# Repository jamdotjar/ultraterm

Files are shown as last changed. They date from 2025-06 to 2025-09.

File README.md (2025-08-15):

# ULTRATERM
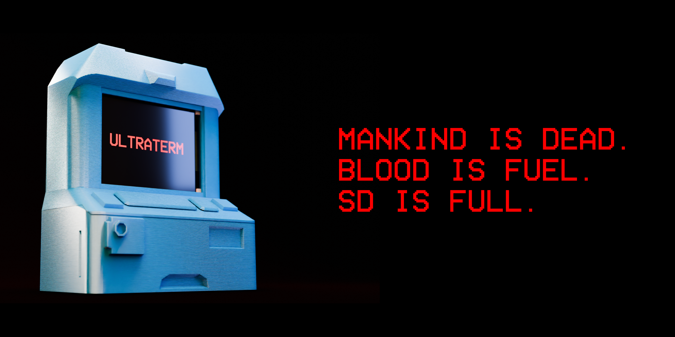
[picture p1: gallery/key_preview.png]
Hero image


ULTRATERM is a miniature replica of an ULTRAKILL settings terminal ( like the one used in cybergrind ), that acts as a bluetooth audio player.

> ***NOTE**: This project is built, but there's still work to do. Check out the [journal](JOURNAL.md) for progress updates! Right now I'm:* `bashing together some code`

## Design

The terminal sits at around 125mm tall, with a 57x104mm footprint. It was designed to look cool, be fairly accurate, and act as a (mostly) stand alone device. It features a:
- 2.8" TFT display
- Touchscreen + 3 physical buttons
- A 2000mAh battery
- Bluetooth headphone support
- USB-C storage interface
- Removable SD card storage ( and a custom microSD card adapter )
The case is designed to be entirely 3D printable, and assembled without adhesive or fasteners.
While the terminal isn't a perfect replica, it's decently close. ( for example, there's none of the wires near the top, but there is a magnetic attachment point so I *can* add them )

This project was made as mostly a fun intro to custom hardware. I've made keyboards before, but design wise those are fairly simplec ( this isn't much more complicated ). I decided to model it after the ULTRAKILL Cybergrind terminal because that's the one that handles  cybergrind music ingame ( and because its form factor is also a *lot* more forgiving to fit everything into )

If you happen to try and make your own, I'd suggest either 3d-printing it in blue for minimum effort, or printing it in grey, painting it, then scuffing the paint to give it the worn look it has in-game. ( also check out the assembly section )

I'm still hacking away at getting everything working, but here's a video demo of my progress so far:

Video (https://www.youtube.com/watch?v=Mtm72WqqxwA)

## Gallery

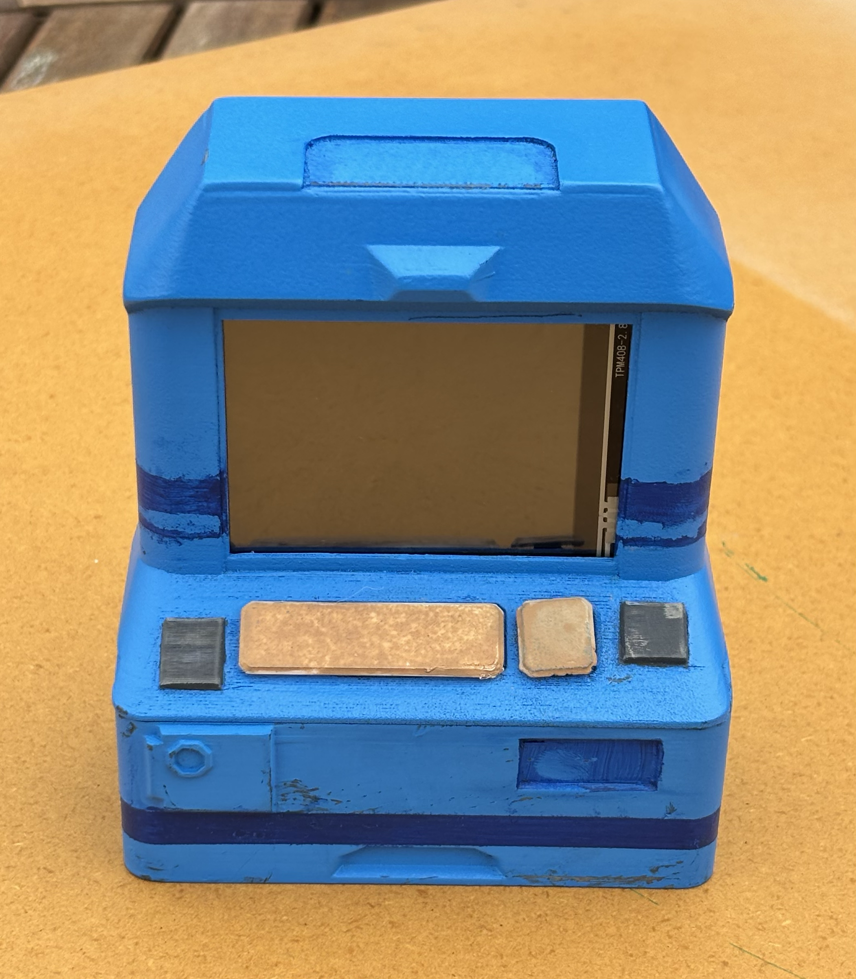
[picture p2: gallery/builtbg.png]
Assebled on tan bg

ULTRATERM back IO render product render on black background
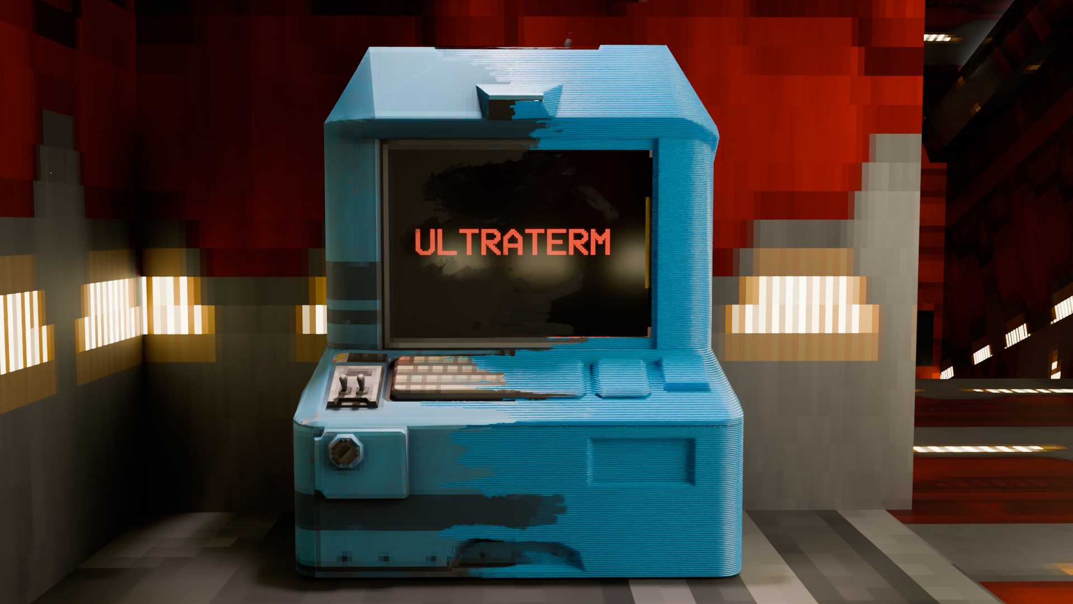
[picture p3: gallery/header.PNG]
ULTRATERM product render in ULTRAKILL enviroment

ULTRATERM left angle product render on black background
*more in [./gallery](gallery)*

## PCB

Screenshot 2025-07-03 at 11 37 43 PM
Screenshot 2025-07-03 at 11 37 01 PM


## Case
Screenshot 2025-07-03 at 11 41 00 PM
Screenshot 2025-07-03 at 11 40 50 PM

Screenshot 2025-07-03 at 11 45 09 PM
Screenshot 2025-07-03 at 11 44 03 PM

### Wiring



## BOM 
*prices in usd, see [bom.csv](/BOM.CSV) too*
|Item |Quantity|Price|Supplier  |Notes |link |
|---|---|-----|---|---|---|
|PCB |5 |4.7  |JLCPCB | |https://jlcpcb.com/ |
|TINYPICO v2 |1 |20 | Digikey |(+20 dollar shipping, ik its really expensive, I csn cover a good bit of the cost )|https://www.mouser.com/ProductDetail/392-TP-01 |
|TZT 240x320 2.8" SPI ST7789V LCD Touch Panel|1 |7.09 |Aliexpress| |https://www.aliexpress.com/item/1005004557916570.html |
|3.7v 2000mah LiPo battery |1 |16.92|Amazon |price comparable to ali |https://www.amazon.ca/Rechargeable-Controller-CUH-ZCT1-Electronic-Bluetooth/dp/B0CG178SHB |
|Pin Headers |20 |2.00 |Aliexpress|for stupid LCD mounting soln. |https://www.aliexpress.com/item/4000873858801 |
|22Awg wire |5m |2.4  |Aliexpress|front panel mount + battery backup soln |https://www.aliexpress.com/item/1005004712828392.html |
|32gb microSD card |2 |4.7  |LCSC |second waives 3$ fee, saves 1 dollar on order total |https://lcsc.com/product-detail/Storage-products_SDTRUVAL-SDSDQAD-016G-SDWCK_C42416577.html |
|32gb SD card |1 |5.8  |LCSC | |https://lcsc.com/product-detail/Storage-products_MK-MKSD032G-CGT1A_C22374946.html |
|LM809 |1 |0.66 |LCSC | |https://lcsc.com/product-detail/Supervisor-and-Reset-ICs_Texas-Instruments-LM809M3X-4-38-NOPB_C544520.html|
|JST-PH-2 |10 |0.59 |LCSC | |https://lcsc.com/product-detail/Wire-To-Board-Connector_JST-B2B-PH-K-K-LF-SN_C265438.html |
|SPDT slide switch |20 |0.48 |LCSC | |https://lcsc.com/product-detail/Slide-Switches_SHOU-HAN-SK12D07VG4_C393937.html |
|6mm pushbutton |50 |0.84 |LCSC | |https://lcsc.com/product-detail/Tactile-Switches_SHOU-HAN-TS665CJ_C393938.html |
|Amphenol 10067847-001RLF |1 |1.31 |LCSC | |https://lcsc.com/product-detail/SD-Card-Memory-Card-Connector_Amphenol-ICC-10067847-001RLF_C569097.html |
|Hirose C719027 |1 |1.04 |LCSC | |https://lcsc.com/product-detail/SD-Card-Memory-Card-Connector_HRS-Hirose-DM3D-SF_C719027.html |
|LCSC Shipping | |12.88|LCSC | | |
|Total |1 |95.21| | | |
## Assembly

Putting this together is relatively simple, the hardest part is connecting the screen and front panel before putting the two halves together. Assuming you aren't too rough, the mounting holes for the screen and button panels should be enough to hold them. A small dab of superglue can help make sure they don't come out with repeated use. I'd advise dupont cables or soemthing similar to connect the screen, as long as it has a lot of slack it should be fine ( the case has a lot of empty space to wind the cables into )
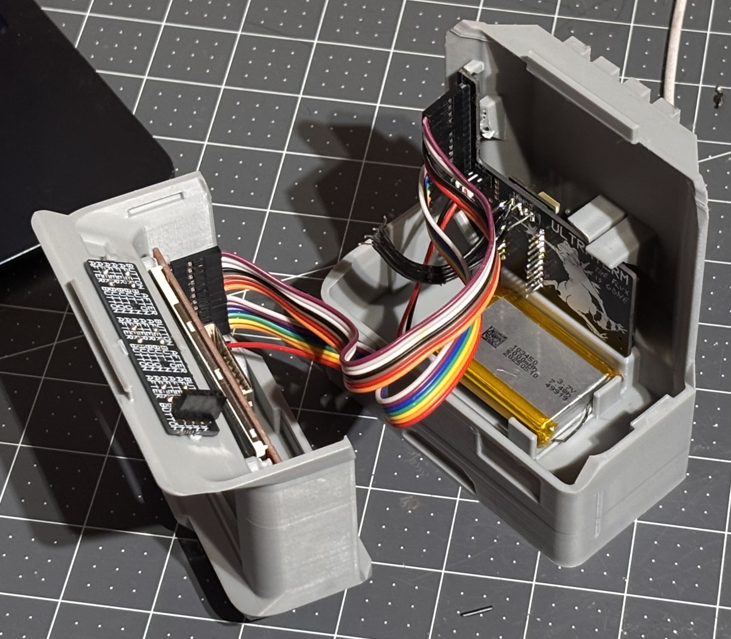
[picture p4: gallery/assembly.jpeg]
Assebled halfway


## LICENSE

This project uses the [CC-BY-SA-4.0](https://creativecommons.org/licenses/by-sa/4.0/) for all firmware, documentation, renders, and other writing. Hardware including all Case and PCB designs, is licensed under the [CERN-OHL-W v2](https://ohwr.org/cern_ohl_w_v2.txt)
> This project was heavily inspired by the game ULTRAKILL, created by Hakita (Arsi "Hakita" Patala). The ULTRATERM design, as well as some assets used in renders are derived from or inspired by ULTRAKILL.
All rights to ULTRAKILL belong to Hakita and New Blood Interactive. This project is not affiliated with or endorsed by Hakita or New Blood. 
( [ULTRAKILL is a banger game, you should totally get it, it's like 20 bucks ](http://devilmayquake.com))

This project was made for [*highway*](https://highway.hackclub.com)

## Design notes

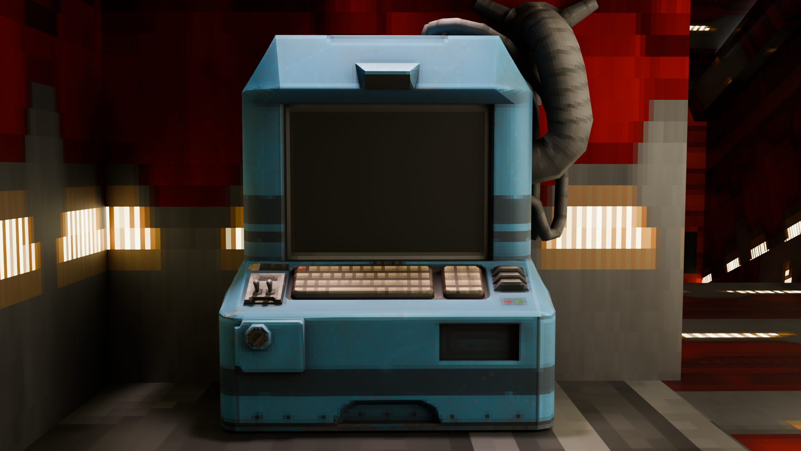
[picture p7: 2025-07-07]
gallery/ent-original.png

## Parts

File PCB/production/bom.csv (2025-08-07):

Designator | Footprint | Quantity | Value | LCSC Part #
J4 | SD_Card_Device_16mm_SlotDepth | 1 | SD_Card_Device
J5 | microSD_HC_Hirose_DM3D-SF | 1 | Micro_SD_Card

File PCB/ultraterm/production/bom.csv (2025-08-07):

Designator | Footprint | Quantity | Value | LCSC Part #
J1 | PinHeader_1x14_P2.54mm_Vertical | 1 | ILI9341
J2 | JST_PH_B2B-PH-K_1x02_P2.00mm_Vertical | 1 | Battery_plug
J3 | AMPHENOL_10067847-001RLF | 1 | SD_Card_Receptacle
J4 | SD_Card_Device_16mm_SlotDepth | 1 | SD_Card_Device
J5 | microSD_HC_Hirose_DM3D-SF | 1 | Micro_SD_Card
LED1 | LED_D5.0mm-4_RGB_Wide_Pins | 1 | LED_5mm_RGB_Kcom_RKGB
MOUSE-BITE-3MM-SLOT_3, MOUSE-BITE-3MM-SLOT_2, MOUSE-BITE-3MM-SLOT | mouse-bite-3mm-slot | 3 | VAL**
R1 | R_Axial_DIN0207_L6.3mm_D2.5mm_P10.16mm_Horizontal | 1 | 33ohm
SW1, SW2, SW3 | SW_PUSH_6mm | 3 | SW_Push
SW4 | SW_Slide_SPDT_Angled_CK_OS102011MA1Q | 1 | SW_SPST
U2 | SOT-23 | 1 | LM809
U3 | TINYPICO | 1 | ~

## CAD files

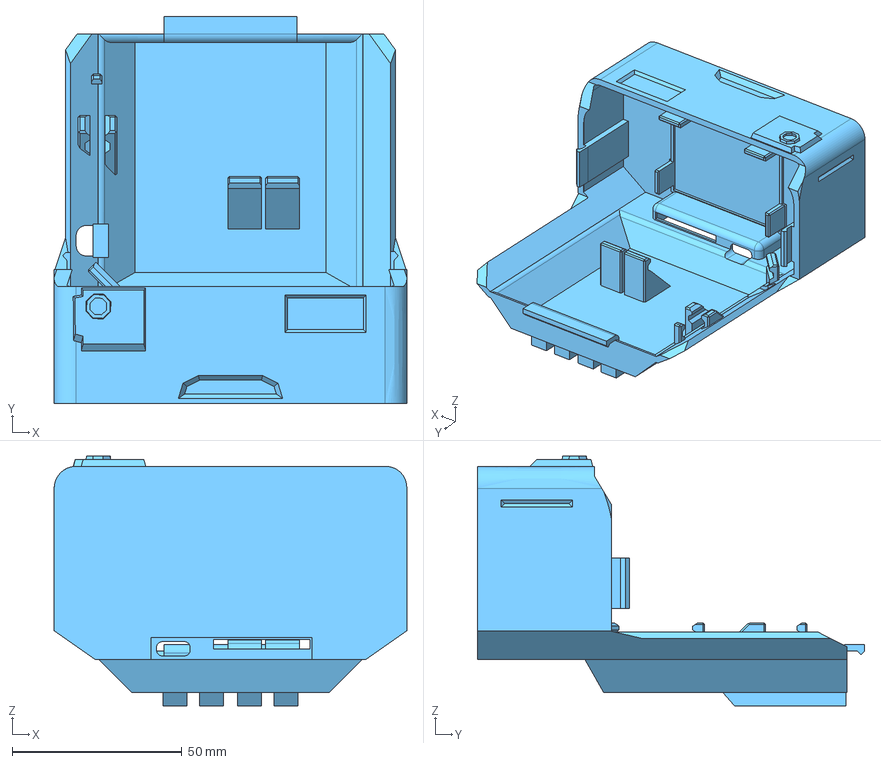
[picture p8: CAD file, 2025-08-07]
Cad/case_bottom.step
104.0 x 114.1 x 73.7 mm

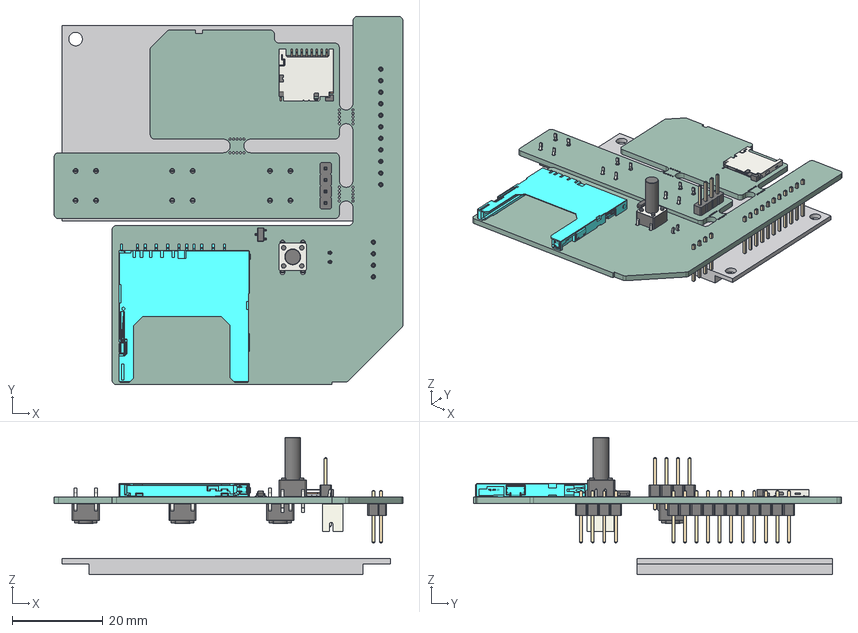
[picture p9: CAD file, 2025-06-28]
PCB/ultraterm/ultraterm.step
76.8 x 81.0 x 30.2 mm
PinHeader_1x04_P2.54mm_Vertical x 2
microSD_HC_Hirose_DM3D-SF
SD_Kyocera_145638009511859+
SW_PUSH_6mm_H13mm
SOT-23
SW_PUSH_6mm x 3
JST_PH_B2B-PH-K_1x02_P2.00mm_Vertical
PinHeader_1x11_P2.54mm_Vertical
240x320-2.4
ultraterm_PCB

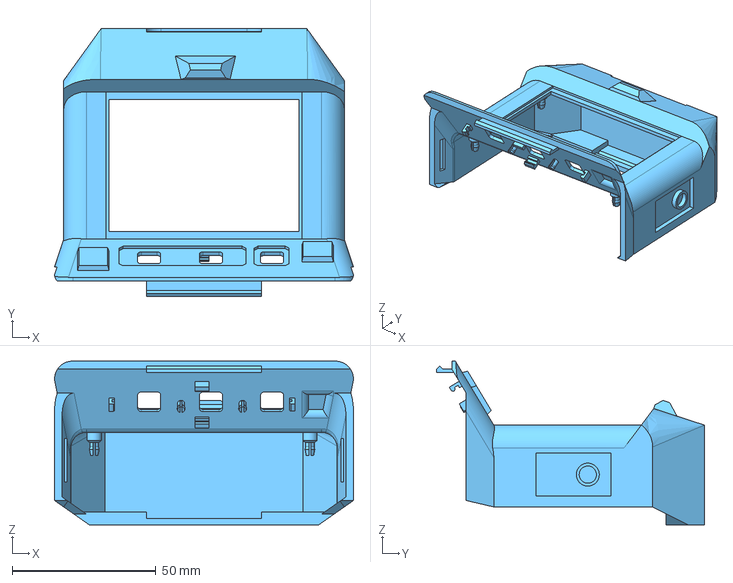
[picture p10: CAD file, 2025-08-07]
Cad/case_top.step
104.0 x 93.1 x 57.0 mm

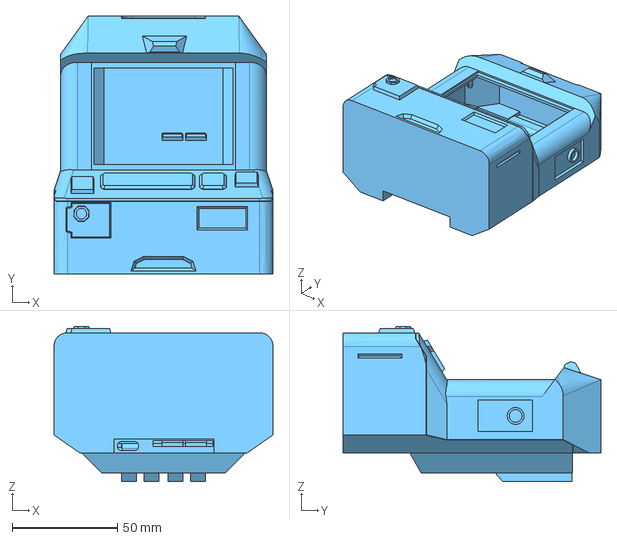
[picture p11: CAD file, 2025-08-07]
Cad/case v11.step
104.0 x 122.5 x 73.7 mm

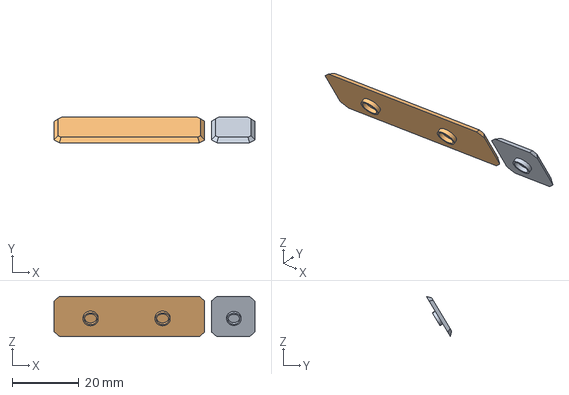
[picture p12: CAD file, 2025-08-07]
Cad/case_buttons.step
60.0 x 7.61 x 12.0 mm

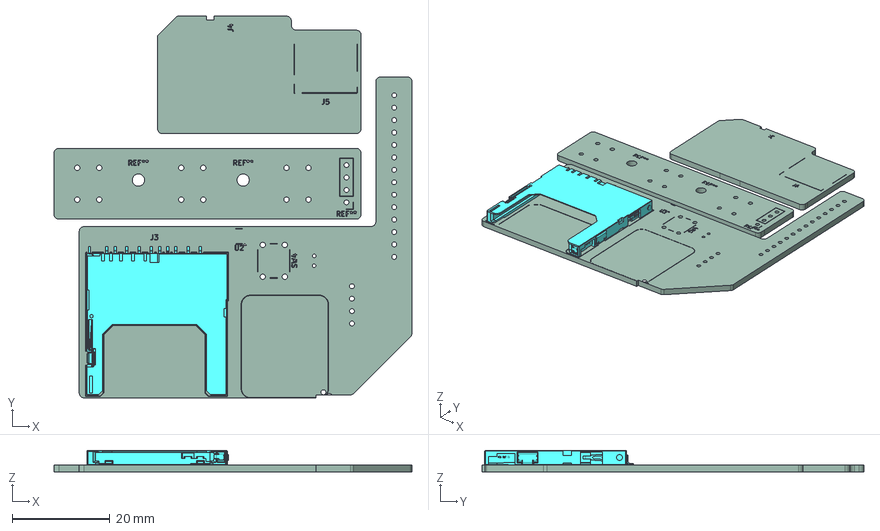
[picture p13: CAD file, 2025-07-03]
Cad/pcb.step
73.1 x 78.0 x 4.52 mm
SD_Kyocera_145638009511859+
ultraterm-nobites_silkscreen
ultraterm-nobites_PCB_1
ultraterm-nobites_PCB_2
ultraterm-nobites_PCB_3

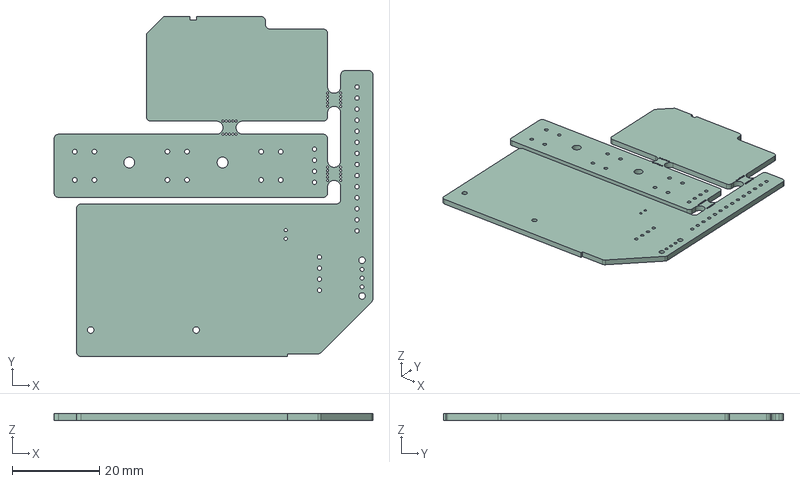
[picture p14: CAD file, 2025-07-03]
Cad/pcbthatone.step
73.1 x 78.0 x 1.51 mm

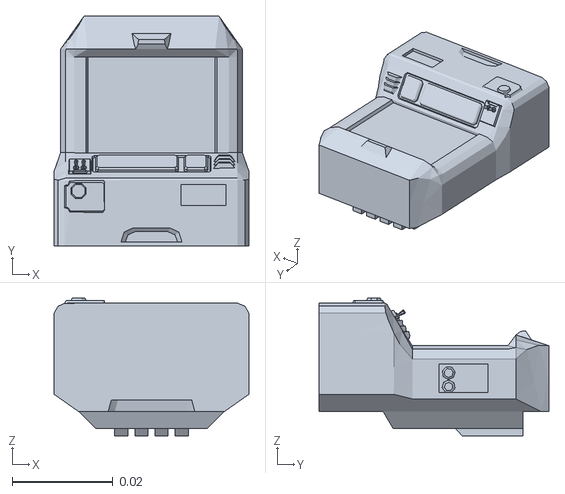
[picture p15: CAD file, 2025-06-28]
Cad/cyberterm.obj
0.0388 x 0.0457 x 0.0274

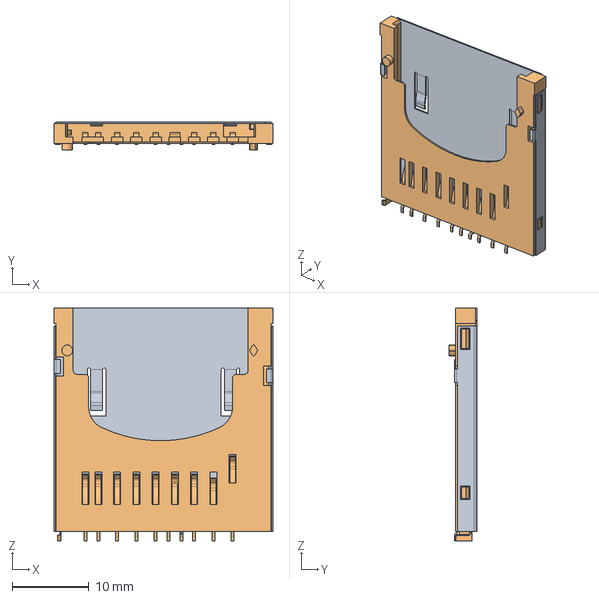
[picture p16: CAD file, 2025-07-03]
PCB/ultraterm/XAIO/10067847-001RLF.step
28.4 x 3.60 x 30.3 mm
PRT0003
PRT0005

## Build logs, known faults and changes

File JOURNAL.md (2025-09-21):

---
title: "ULTRATERM"
author: "Finn H"
description: "A bluetooth MP3 player styled as a miniature replica of the ULTRAKILL cybergrind terminal"
created_at: "2025-05-19"
---

# ULTRATERM Journal

> *time spent up to when this was last changed: 60hrs*

### 2025/05/19 ( and the past 3 days I didnt journal )
This has been mostly just research on *how* I'm actually pulling this off. I've ( tenatively ) setteled on this as a **very rough** list of what I'll use:
- ESP32s3
- Some sort of small TFT display
- microSd reader
- rotary encoder?
- headphone jack
- some buttons ?
- rechargeable battery?
I still need to figure out the best input methods, as well as whether a battery is super important for the design. I think it would be a nice bonus, but not nessicary if the footprint gets too tight.
I also started to gather references for the design, not sure whether to go for the pre or post revamp termial model for inspo. ( these frickers )




Scraped ultrakill assets for raw files, need to actually find the terminal now



> *time spent: ~4 hrs over the last 3 days?*

### 2025/06/04
OK, so it's been a while. I kinda dissapeared so i could speedrun solder, and resign my hackboard case to practice CAD. 
I've semi-settled on a ~2.4 inch display~, it didnt fit, so I'm starting to design the case based off of it. It was a pain to scrape the ultrakill models, but I'm in love with the design of the cybergrind terminal, ( there's a section on the back that's just begging for a SD card slot :3 )



The basic case shapes are done, so I'm going to start to try laying out part locations, and then I'll get on the PCB! I changed to a 2.8 inch display ( A  ILI9341 ), so I can finalize a parts list around that now!



> *time spent: 3 hrs*

### 2025/06/21 
Ahhhhhhh, there was so much to do. Now I guess I have to speedrun this in two weeks.
ESP32 variant changed to a SEEED Xaoi esp32s3 for the smaller form factor, and builtin battery charging. 
The final parts list is
- XAIO Esp32s3
- ILI9341 2.9 inch TFT display
- [2k mAH liPo](https://www.aliexpress.com/item/1005008129110763.html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)
- JST PH 2.0 socket
- 3 buttons ( idk what kind will fit yet )
- MicroSD card reader
- TRRS jack
I also figured out that there's a very convenient little notch on the back where all of the io fits perfectly, which I'm very happy about, although it does make me a little scared about how big this will actually be



I've dumped all of the parts into kicad so now I just need to figure out how to actually connect it to the MCU, I'm slightly worried about the limited pin count, i might need to cut the TRRS jack, but I'm not too invested in that.



> * time spent: 2hrs*

### 2025/06/25
Picking up from where I was last time, i'm trying to figure out how to interface with the SD card in SPI mode so I'm reading through the specifications for that. Also debating whether a touchscreen would be better. It is more lore accurate, and it might make interfacing easier, but I'm not sure if the cost/complexity overhead is worth it. I'll look into it more after the microSD card bit is done. 
After about an hour of bashing my head against the wall, it turns out the SD card can be wired directly to my MCU... fun. 
The schematic is finished, the display has changed once again to a model with basic resistive touch. At worst it's a dollar or so more expensive, and at best UX is a lot easier to design.
Ther schematic so far:



I'm curretntly really far into trying to figure out how to wire the reset pin to power so it automatically resets when the device turns on, finally figured out I just needed a LM809



Now for PCB, The main thing is making all the IO line up with the bottom port, and having the screen be in roughly the right spot as well. The front buttons will probably need to be a seperate PCB somehow. From my estimations in fusion, there will be a 36mm gap between the bottom of the LCD and the bottom of the IO, which *should* be enough to fit everything.

> *time spent: 4hrs 😭*

### 2025/06/26
I'm trying to figure out the PCB layout, the three main  struggles are how to connect the buttons, where the power switch goes, and how to get the IO to fit in it's slot. 

Some finagiling later I've decided that I'm just leaving a really thin little spindle to get the display connector, and then use the blank space for a seperate button plate, and potentially a microsd card adapter. This is what the layout looks like *so* far, hopefully I dont need many changes for routing. I'm mainly trying to keep this under the 100x100mm jlcpcb cheap factor.



> *time spent: 3hrs*

### 2025/06/27
The PCB had a bit of extra room near the top, so I added a small microSD to SD card adapter. Mainly a convenience thing, so I can use both, and this way I can put whatever silkscreen I want on it.



The board is structurally complete, and fully panelized, now I just need to figure out how to fit everything into the case. Something tells me mounting these is going to be a bit of a pain. (ignore the blue sc card reader)



PCB is done though, so i'm happy abt that. 
Never mind. I forgot the orginal was desinged around a 2._8_ inch screen, so now the positioning is all off. Time to go fix that, yayyyyy.
The midnight grind session has brought many fruits. first, I found a suitable display replacement on aliexpress. Most displays had the pins below the holes, but I needed one with them between them so it would fit in the case ( from rough estimations ).




After making a new footprint, remeasuring my case, and moving it on the PBC. It took a while to reroute the extra pins, but I'm confident it'll be for the last time. 



> *time spent: 6hrs*
### 2025/06/08
I brought the PCB into cad to check the dimensions one final time. 

Aaaand, kicad is refusing to export my step files with 3d component models. All it's exprorting now is the fricking SD card slot, I have 0 clue why ( it worked fine an hour ago, which is how long i've been trying to fix this stupid problem )
I still don't know why it wasn't working, but I added the missing components in fusion, so it's fine now. 
After a bit of fiddling, here's it all laid out. 




The next step is to make the solid block the case currently is into a proper shell, and add some things to help mount the PCB. I started by removing the surface details that would need to be cut out, and then I made the main case into a shell. To determine the wall thickness, I was having a tough time actually visualizing *how* each thickness would fare, so I printed out some samples for 1, 2 and 3mm.
testcubes
As expected, 1 suffered from flimsiness and light bleed. 3 was close to what I needed, but it was just a touch thick so I went with 2.5mm. This was half an hour for a decision between three numbers, I might need to reprioritize where I'm spending my time.

Given I need to actually assemble this case, my main concern is how I'll split the body so it can go together in a somewhat reasonable manner. I  sketched up a few different options, trying to get a sense fro how to hide seams, while keeping it fairly easy to assemble.

In the end, it makes the the most sense to me to cut it horizontally, similar to the blue line. (as well as potentially letting the bottom come off)




wrangling with fusion made today a bit of a slow day. I'm hoping to finish the case over the next two days, so I can whip up a rough version of the firmware, and polish the project for shipping. 

> *time spent: 4hrs*

### 2025/06/29

Most of today's work was solely focused on making a decent case in fusion. I spent way too long trying to figure out how to actually split the shell as I'd planned, and the initial split was really janky, which required a bit of clean-up, but now everything looks good.


My biggest problem with the case is making sure that A: it looks at least *somewhat* like the real deal. B: The parts actually fit inside, and stay where they're supposed to.

Scraping the game files for a reference back on the very first day mostly dealt with the accuracy concenrns ( hopefully my paint skiolls will be able to patch up the rest — wait, crap, skills. hmm, maybe I'll just get some blue filament )

As for the parts fitting, I have *no clue* how that's gonna work. I know where they need to be, and while just supergluing them in, or encasing the entire thing in resin might *seem* convenient. I have a sneaking suspicion that that is a terrible idea, so I spent way to long thinking before I realized I can just use snap tabs. 



After modeling them, I realized that they were clipping out of the back of the case, and proceeded to go mad trying to fix it. 
The above sentence was written before I tried to do that, after writing, I did it wrong, second guessed myself, and wasted 30 minutes trying objectively worse solutions. Moral of the story is trust your gut or something I guess.



In other news for today, I added the IO cutouts, I grill on the back I missed for some reason, and a screen cutout 




> *time spent: 4hrs*

### 2025/06/30

After (sorta) figuring out mounting for the PCBs yesterday, I spent most of today adding mounting points for the screen, button panel, and battery ( which I kinda forgot existed until now ). I'd initially planned for the battery to be 2000 mAh for no reason at all, so I had to double check the expected battery life. I estimate the system will have a power draw of roughly 200mA, meaking the *ideal* battery life would be around 10 hours of constant use, which is totally fine by me. Worst comes to worst, the battery can just be swapped out, because I included a standard JST 2.0mm connector 👍

I also added more snap-fit connectors to the case itself, so it can actually fit together ( and come apart ) all without any fasteners, which was one of my goals from the begininning.
Once that was done, I finished by adding in all the details I forgot to model earlier, all the little slots, panels, and other sci-fi greebles. Anyways, since most of the changes were just small modelling changes, here's a screenshot dump:













With that, I'd say the case is actually complete, leaving me ( technically ) 2/3 of the way through this process. The last step is a basic firmware, which only needs to do 3 things.
1. Connect to bluetooth headphones
2. Read and playback from the SD card
3. Display controls for the above onscreen
Once that's all done my stretch goals are to:
- make it look as game accurate as possible
- Let people upload files to the device either wirelessly, or when plugged in.

> *time spent: 4hrs*

### 2025/07/01
I started trying to get some sort of firmware made today. The first step was trying to figure out *how* to go about embedded firmware. A bit of googling led me to PlatformIO which seemed simple enough, while still giving me a fair amount of control. Luckily, I had an esp32s3 devboard lying around, so I can actually test at least part of my code. ( The bluetooth function, specifically and maybe the SD card if I'm feeling like soldering to the pads of one ). As of right now, I have uploaded some test code, but not much past that. 

I took a bit of a break to make my BOM, because I'm pretty confident with the physical design at this point. Unfortunately, I did have to go back and edit my PCB as the SD card connecter I had chosed turns out to be discontinued.
It also turns out the power switch I was using was not a toggle switch, so now I need to find one of those, and figure out where the hell to put it. So, uh, yeah. Awesome day, I've gone backwards. I needed to remodel the case to fit the new switch, so I guess I'll finish the BOM tomorrow, and speedrun some firmware.


> time spent: 3hrs*

### 2025/07/02

I finished the BOM today, which took a bit longer than I expected. Still, it's anothers step towards this being complete so I'm not too pressed about it. After the BOM, I jumped back into the firmware. My main goal for a hopepfully functional MVP is to connect to headphones, play audio to them, and have a button to like, shuffle or something. 

SHIT, the esp32s3 doesn't support A2dp, so now I need a completely differnt chip, that'll be in a different form factor. yay. 
why do things keep going wrong. ( granted, I should have researched better, but I thought the s3 would work ). 

I found a suitable replacement board, the TinyPico. It it a fair bit more expensive, but I'm under budget so I think it's fine. ( also, the other board would have required me to get a hotplate, which would have been an additional $20 anyways ) after a lot of checking, it has everything I need:
- Battery management
- USBC
- Small footprint
- Bluetooth A2DP
So that is now the core MCU, it's based on the esp32-pico d4, and it's going to do a great job. There are no avalable footprints or symbols, so I had to make those, which was a bit of a pain. One good thing to come out of this is that there was a spare few pins, so I was able to add a status indicator LED, something i've wanted to do for a bit. So, at least there was *a singular upside* to today.



I made a footprint, and completely rerouted my PCB. I kept the USB in the same spot, so the case design *should* still work 🙏. Now to hop back to firmware :yay:
> *time spent: six. hours. why. ( update, I worked more so it's actualy like 8 (
>  )

### 2025/07/03

After yesterday's fiasco, I am right back where I was before it all went pear shaped. So, firmware... take two ( with the slight downside that I can't actually test my code now ). 
To start, I tried to figure out what my priorities would be for the first rough draft of my code. After a touch of thinking, I decided on the order of:
- Headphone pairing
- Audio playback
- SD card reading
- Button input
- UI display
- Touch input
- Mass storage device
For this, I'm mostly focusing on the first two for the prototype, then once I get the actual device and can test the rest of the functions, I'll do that.
As for an actual application flow, I think
1. bluetooth pairing
2. Main menu ( shows info )
3. Playback
seems reasonable. I'll probably use LVGL for UI if I get there.

I started off with the bluetooth. I managed to find a library that implemented A2DP audio source for arduino, that also seems to handle the connection logic for devices, so I was ablle to get a simple version of that all set up ( it just tries to pair to the first device it sees, maybe a bit of room for refinement in the future. From there, I started with file reading, to actually provide the audio stream. 

After that, the main goal was to get some sort of interaction and input going. ( and maaaybe some output ). 

> * time spent: 3hrs*

### 2025/07/04

I'm getting pretty close to finishing this, I can feel it. I spent a bit of time last night polishing up the README, so now all I'll need to do is add some nice renders, finish this firmware, and I'm done!

I hopped back into my firmware with the input management, and I got through the first half of a callback system, that should be OK for the buttons. I think the touch might need a seperate handler once I've gotten LVGL running, but in the meantime I've just set it as another "button".

I also had to go and fix some of the storage code, because I'd used the wrong library example as a base, so had to redo the PCM stuff. Now I'm going back to input, and as a last goal I'll try to get a simple state display runnning. I actually think all of my input and playback should work! It all at least compiles, which gives me a fair bit of hope. 

Now for some actual interaction, then I can whip up a 'lil demo UI! I don't want to attempt the final UI until the final version, but it's close! 

I added a basic interaction system, that took way longer than anticipated due to having to handle my multi-core concept of having one handle playback and the other handling input and UI to let both run smoothly. It turns out i forgot how hard communicating between cores is, so I had to use a input queue to handle the audio via button presses, and now I have a basic UI that displays the current playback state.

For my last change to the protoUI, I converted the VCR_OSD_MONO font from ultrakil to LVGL C, so I can use it as the main font for my UI.

Tomorrow goals are to polish the demo UI, README, and CAD to make sure everything is ready for submission ( and hopefully submit too ), after that, there will likely be some more work on the final UI. I think LVGL lets you preview the UI somehow so I'll look into that, because anything I can prototype before I get my parts is good. Once I do get my parts, I'll also journal the assembly, and road to a physical v1, so stay tuned.

> *time spent: 3hrs*

### 2025/07/05

*sucess*
I was busy most of today, but I did manage to get my firmware to compile in the state I want it to which at this point is my only real metric for whether or not it will work. Once I was happy with that, I turned my attention back towards the readme, as I wanted some images to put in the gallery. I needed some simple renders in blender, showing what the whole thing might look like. I also wanted one, more stylized "header" image to go right at the top. I didn't have a photo of the in-game terminal anywhere in the readme so far, so including it in this seemed like a good idea. Since this would be *the* headliner image, I decided to actually give it an ounce of planning.  What I managed to come up with was a scene where it's split between the original terminal and my version, in their respective enviroments. ( hell and desk ). 
I started by importing my terminal into blender, and setting up a material. I decided to try and mimic the texture of a 3d print, which lead to this node setup:

Then I pulled in the actual terminal model ( thanks again to me for scraping it back in may ), and promptly had to go digging around the unity project anyways to find the elevator model. Unity happend to lose every single texture, so I had to resort to the somehwat outdated model collection I found online.

Either way, that got me the entrance area, and let me finally finish setting up my scenes. Yay. On the bright side, I'm actually almost done for real this time™ 

As a last ditch effort for "today" I finished the two component renders for the header. Tomorrow I can do the differnt angles of the main device. 



> *time spent: 4hrs*

### 2025/07/06
Right back into blender today, I spent the morning working on a few more renders. *they're different, trust*



After I was good with the hell reners, I popped back into my void to get some "product photos". I had to adjust the lighting on the blackvoid renders, as it was way too harsh before, so I just went back to a basic 3 point lighting setup.

I just spent the last 4 hours on renders, here's the rest of what I did!





After that, I took the images and tried to combine some together to get a header, and a cutaway view. I also updated the README with Lisences and other legal stuff, and added a lil highway link. I'll add a less little one here, because if you're reading *this* you definitely care enough to check out Hack Club. 

A badge of a Cerberus and a raccoon laughing together, with the text "HIGHWAY" and "HACK CLUB" beside them.

I'm going to ask for some feedback from friends, then I'll submit!

> *time spent: 5hrs*

## 2025/07/20
Another big break, but this time because I went to Undercity. 10/10 experience lol. In the time since then, I've printed out my case, and everything fits. I still need to paint it, but it should be good to go as soon as I get the rest of the parts. Speaking of the rest of the parts, my grant came in today so I could finally start ordering everything. I did, but not before plastering the PCBs with some decoration! 




> *time spent: 2hrs*

## 2025/08/05
So this is what $100 of parts looks like:



All of my parts arrived while I was away, so today was an assembly and soldering marathon. I didn't entirely realize how small some of the parts I had to solder were until I saw them. Tiny SMD components never bring joy to my soul. Luckily I only actually had to deal with three of them. 
Getting off to a great start I broke a pin off of my large SD card reader while opening it's package, which turned into a 30 minute repair attempt. before/after:


.

Besides that repair ( and a bit of a mishap where I put on the power switch backwards ) soldering went suprisingly quickly, especially with the microSD card adapter which I was expecting to be about five times more complicated than it actually was. 

Not much else to say on soldering, exept that it took almost all day. ( the front panel connector kept breaking ok? ). the only connection I have left is the front panel connector, because I realized my header stacking strategy doesn't actually work. 

Actually putting stuff together now. Everything fit in the case really well, although I did have to cull one or two of the mounting pegs, so I'll update the models to reflect that. The LCD mounting strategy I ended up choosing turned out to be just shoving a ton of jumper wires into the case ( good thing I left a bunch of empty space ). I still need to paint the case, but at this point im certain that this will actually work, once I actually get the fricking firmware working. here's some assembly pics:




> *time spent: 6.5hrs*

## 2025/08/06

Paint time!

I did a bit of research on different ways to finish 3d prints, and it seems like the best way to go about this is a few coats of sandable primer, then some spraypaint. Not much more to it. 



I used the primer color as the base grey/metal of the terminal ( brushed with some metallic paint ). Some painted lines, keys, and other stuff later,this is the final result, 100% assembled

 

> *time spent: 5hrs*

## 2025/08/08-2025/08/15
( I forgot to add timestamps or commit so now I can't seperate the entries, according to wakatime this whole block was like 15 hrs of total work )

Holy firmware batman!

The first version of my firmware was based on a lot of (mostly incorrect) assumptions, so flashing it into the device turned into a fun litle excercise in everything going wrong all at once. Considering that every initialization step was failing in isolation and that together it was bascically a rats nest of task calls,  I've decided that in the interest of actually getting it working a rewrite is in order, following this feature priority:
- bluetooth ( because otherwise I have no way of telling if the music playback part works )
- SD card reading/playlist generation
- buttons for playback controls ( skip, pause )
- Screen/status UI
- Other fancy (mostly style) based additions like exposing the filesystem over USB or smth.

A couple hours into v2 of the firmware ( haha, getit, v2 ), and bluetooth is working ( it pairs, heaphones recognise ). The on-chip flash is a pain to store files in tho so I'll have to wait for the SD card stuff to get working before I can test sound. 
SD card is formatted properly, all the files are in WAV but for some reason it's saying the bitrate is 0 ( it's absolutely not ), Im going kinda crazy trying to fix this.

Ok so apparantly the SD card isn't reading at all, I'm kinda suspecting that the CS pin I broke could be causing issues, I don't have a multimeter to test, but there is a SD card slot on the display for some reason I can try wiring into. That worked, and somehow it made the og port start working too?? idk, but I can confirm the playback and SD stuff works now!

I left it for a bit and came back and the SD card stopped working again, idk why, it's the exact same code, exact same hardware setup and everything. 

Spent the last hour fixing this again, all the buttons are properly wired too so I started testing the playlist stuff. Switching to the next song when the last one ends works fine, but skipping songs sometimes doesn't work, or sometimes leads to a bunch of really harsh static that doesn't go away. I think it has something to do with it not being able to read quickly enouch or something, so I'm going to try having it pause before switching songs so it doesn't interrupt anything. 

I ended up doing something a bit more complicated than just pausing, but it seemed to work ( appaerntly the BT loop operates seeprately from main stuff so I queued the changes for whenever it gets to it and pause in the meantime ). Also, the issue with the SD card seems to be somehow related to having the secondary (unused) sd card slot wired up. I guess there's some passive componenets that help with the signals to the main reader, but in practice I'm just calling it the emotional support sd card reader. 

deadline is today, and everything exept for the screen is working, so assuming I can get that configured right, it should be a pretty easy finish. so far it's only been showing a pure white screen though, so I can't really tell what the dealio is. The aliexpress listing had people complaining about a similar issue, so I hope I didn't get a bad unit. 

I've tried all the basic libraries ( arduino GFX, tft_eSPI ) with a bunch of different configurations and I haven't been able to get any communication happening. I'm pretty sure whatever driver ( I think it's the st7789v ) I have doesn't actually use the MISO pin, so I cant get any output from the display exept for visual ( which is not going well ). 

I spent the last couple hours trying to find a solution, and the closest I got was some very faint RGB noise showing up on the display. After that, the USB serial comms broke for some reason, so by the time I got that working again I just had to load up the mostly working firmware. I'm kinda dissapointed the display isn't working, but out of everything to break, it's still the least critical. 

Finally demoed!

> Time spent in this massive block (thx wakatime): ~13hrs

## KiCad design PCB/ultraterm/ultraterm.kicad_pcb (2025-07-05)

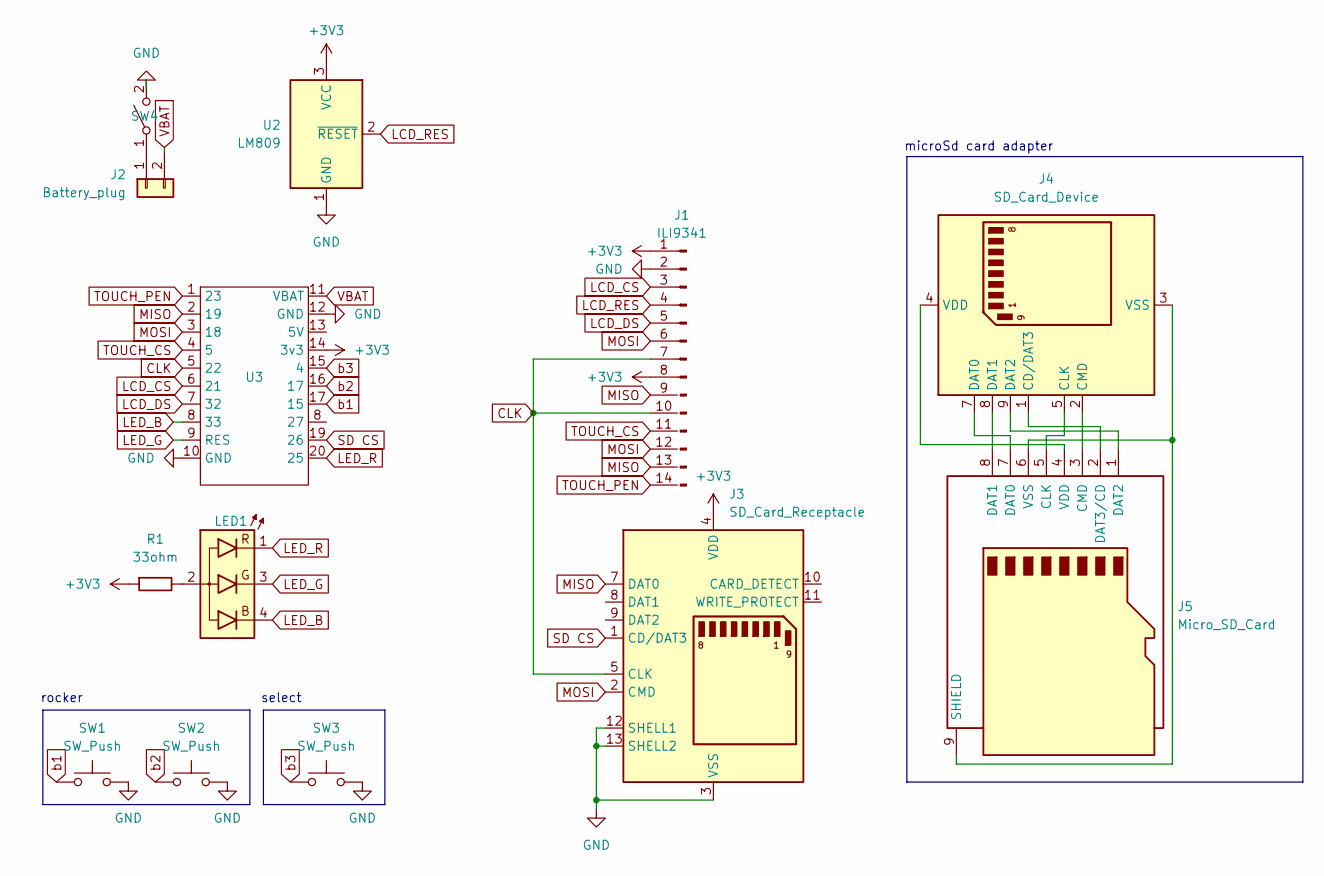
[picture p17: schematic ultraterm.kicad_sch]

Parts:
J1: ILI9341; PinHeader_1x11_P2.54mm_Vertical
J2: Battery_plug; JST_PH_B2B-PH-SM4-TB_1x02-1MP_P2.00mm_Vertical
J3: SD_Card_Receptacle; SD_Hirose_DM1AA_SF_PEJ82
J4: SD_Card_Device; SD_Card_Device_16mm_SlotDepth
J5: Micro_SD_Card; microSD_HC_Molex_104031-0811
LED1: LED_5mm_RGB_Kcom_RKGB; LED_D5.0mm-4_RGB_Wide_Pins
R1: 33ohm; R_Axial_DIN0207_L6.3mm_D2.5mm_P10.16mm_Horizontal
SW1, SW2, SW3: SW_Push; SW_PUSH_6mm
SW4: SW_SPST; SW_SPST_Omron_B3F-315x_Angled
U2: LM809; SOT-23
U3: TINYPICO

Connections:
+3V3: J1.1 (VCC), J1.8 (LED), J3.4 (VDD), R1.1, U2.3 (VCC), U3.14 (3v3)
CLK: J1.7 (SCK), J1.10 (CLK), J3.5 (CLK), U3.5 (22)
GND: J1.2 (GND), J3.3 (VSS), J3.6 (VSS), J3.12 (SHELL1), J3.13 (SHELL2), SW1.2, SW2.2, SW3.2, SW4.2 (B), U2.1 (GND), U3.10 (GND), U3.12 (GND)
LCD_CS: J1.3 (CS), U3.6 (21)
LCD_DS: J1.5 (DC/RS), U3.7 (32)
LCD_RES: J1.4 (RESET), U2.2 (~RESET)
LED_B: LED1.4 (B), U3.8 (33)
LED_G: LED1.3 (G), U3.9 (RES)
LED_R: LED1.1 (R), U3.20 (25)
MISO: J1.9 (MISO), J1.13 (T_DO), J3.7 (DAT0), U3.2 (19)
MOSI: J1.6 (MOSI), J1.12 (T_DIN), J3.2 (CMD), U3.3 (18)
unnamed: J2.1, SW4.1 (A)
unnamed: J4.1 (CD/DAT3), J5.2 (DAT3/CD)
unnamed: J4.5 (CLK), J5.5 (CLK)
unnamed: J4.2 (CMD), J5.3 (CMD)
unnamed: J4.7 (DAT0), J5.7 (DAT0)
unnamed: J4.8 (DAT1), J5.8 (DAT1)
unnamed: J4.9 (DAT2), J5.1 (DAT2)
unnamed: J4.4 (VDD), J5.4 (VDD)
unnamed: J4.3 (VSS), J4.6 (VSS), J5.6 (VSS), J5.9 (SHIELD)
unnamed: LED1.2 (A), R1.2
SD CS: J3.1 (CD/DAT3), U3.19 (26)
TOUCH_CS: J1.11 (T_CS), U3.4 (5)
TOUCH_PEN: J1.14 (T_IRQ), U3.1 (23)
VBAT: J2.2, U3.11 (VBAT)
b1: SW1.1, U3.17 (15)
b2: SW2.1, U3.16 (17)
b3: SW3.1, U3.15 (4)

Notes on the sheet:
microSd card adapter
rocker
select

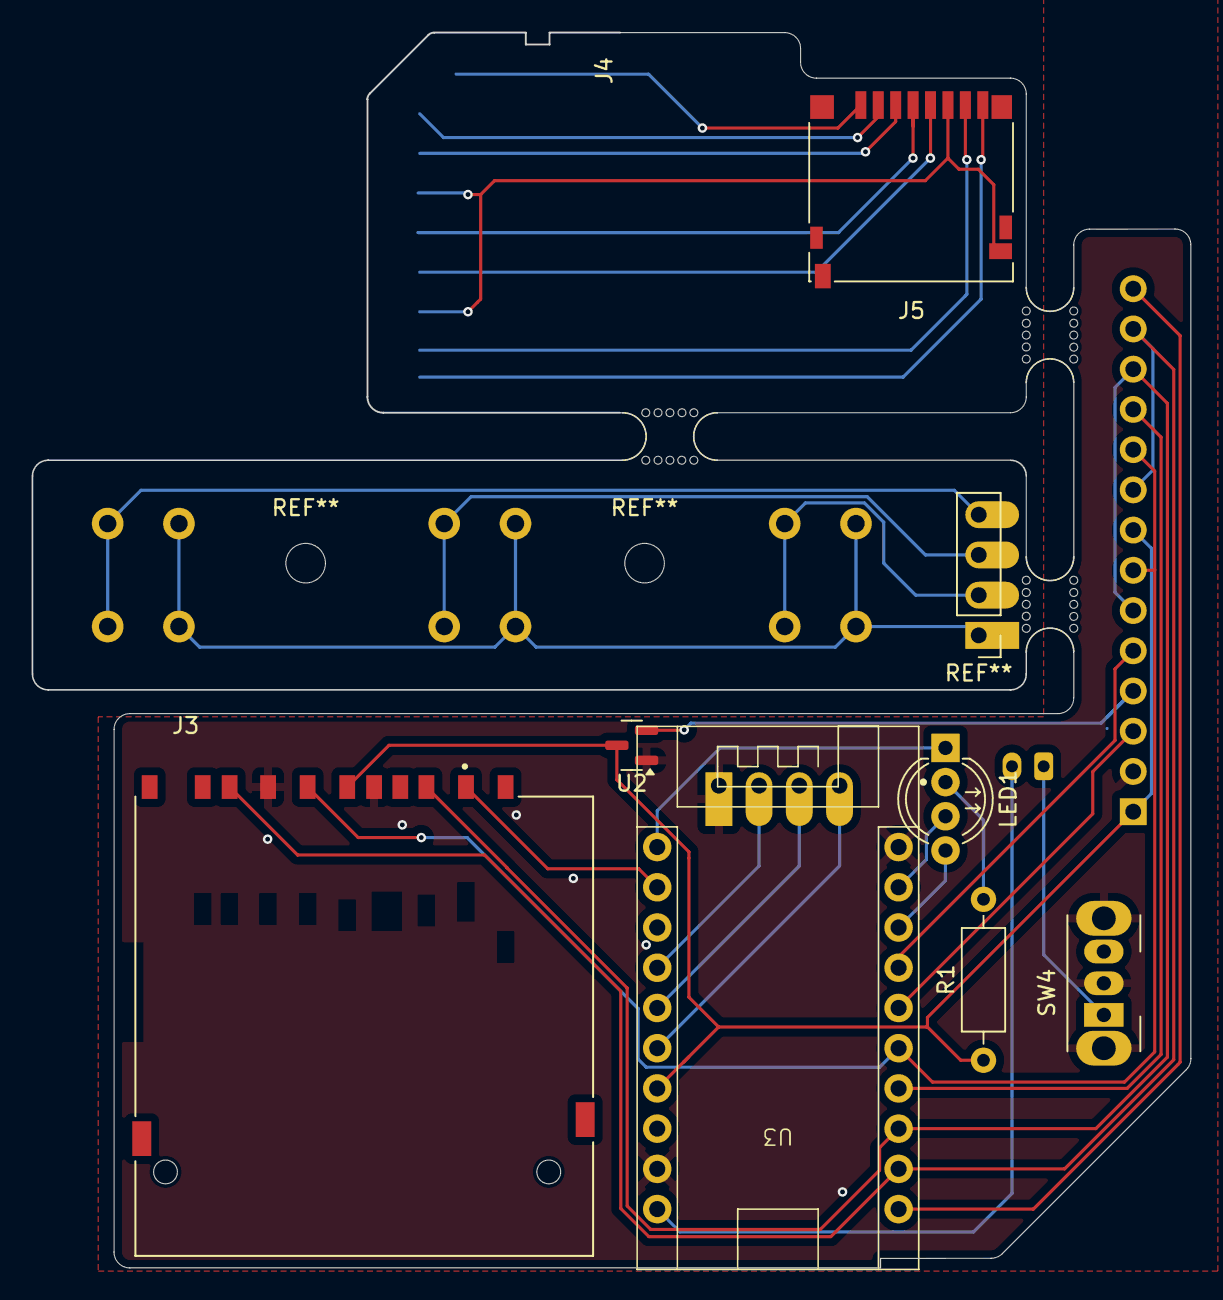
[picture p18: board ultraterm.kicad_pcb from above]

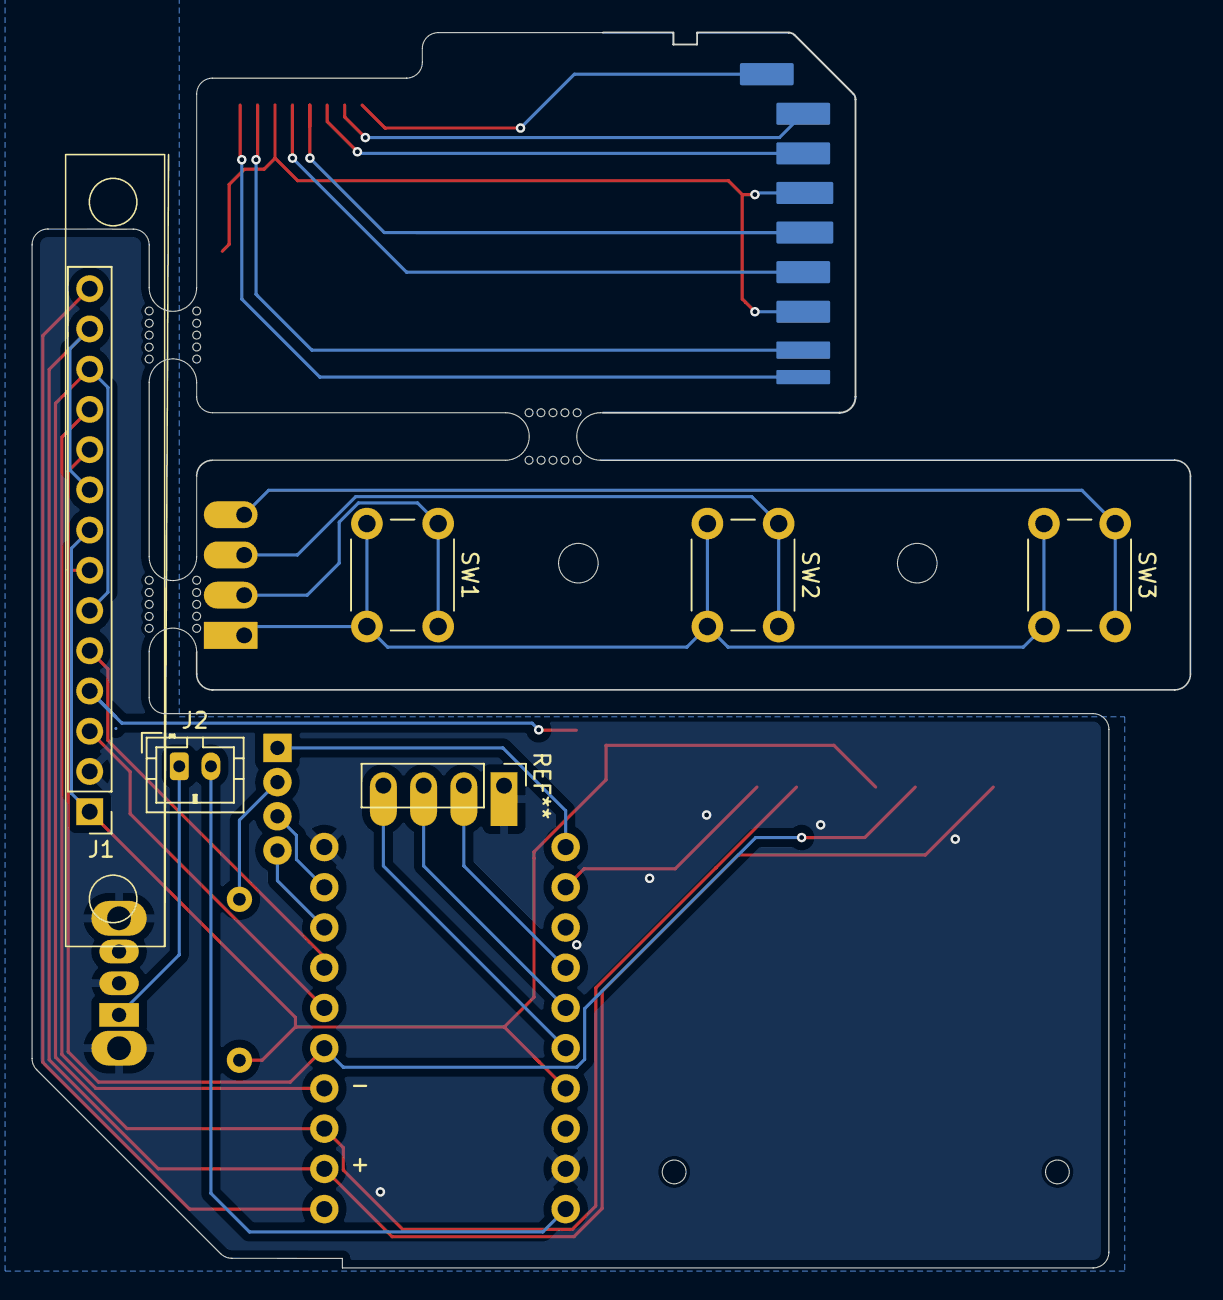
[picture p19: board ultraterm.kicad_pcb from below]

Board: 2 copper layers, 73.1 x 78.0 mm, 16 parts (5 on the bottom side), 28 nets.

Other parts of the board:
mouse-bite-3mm-slot, mouse-bite-3mm-slot#2, mouse-bite-3mm-slot#3: VAL**; mouse-bite-3mm-slot

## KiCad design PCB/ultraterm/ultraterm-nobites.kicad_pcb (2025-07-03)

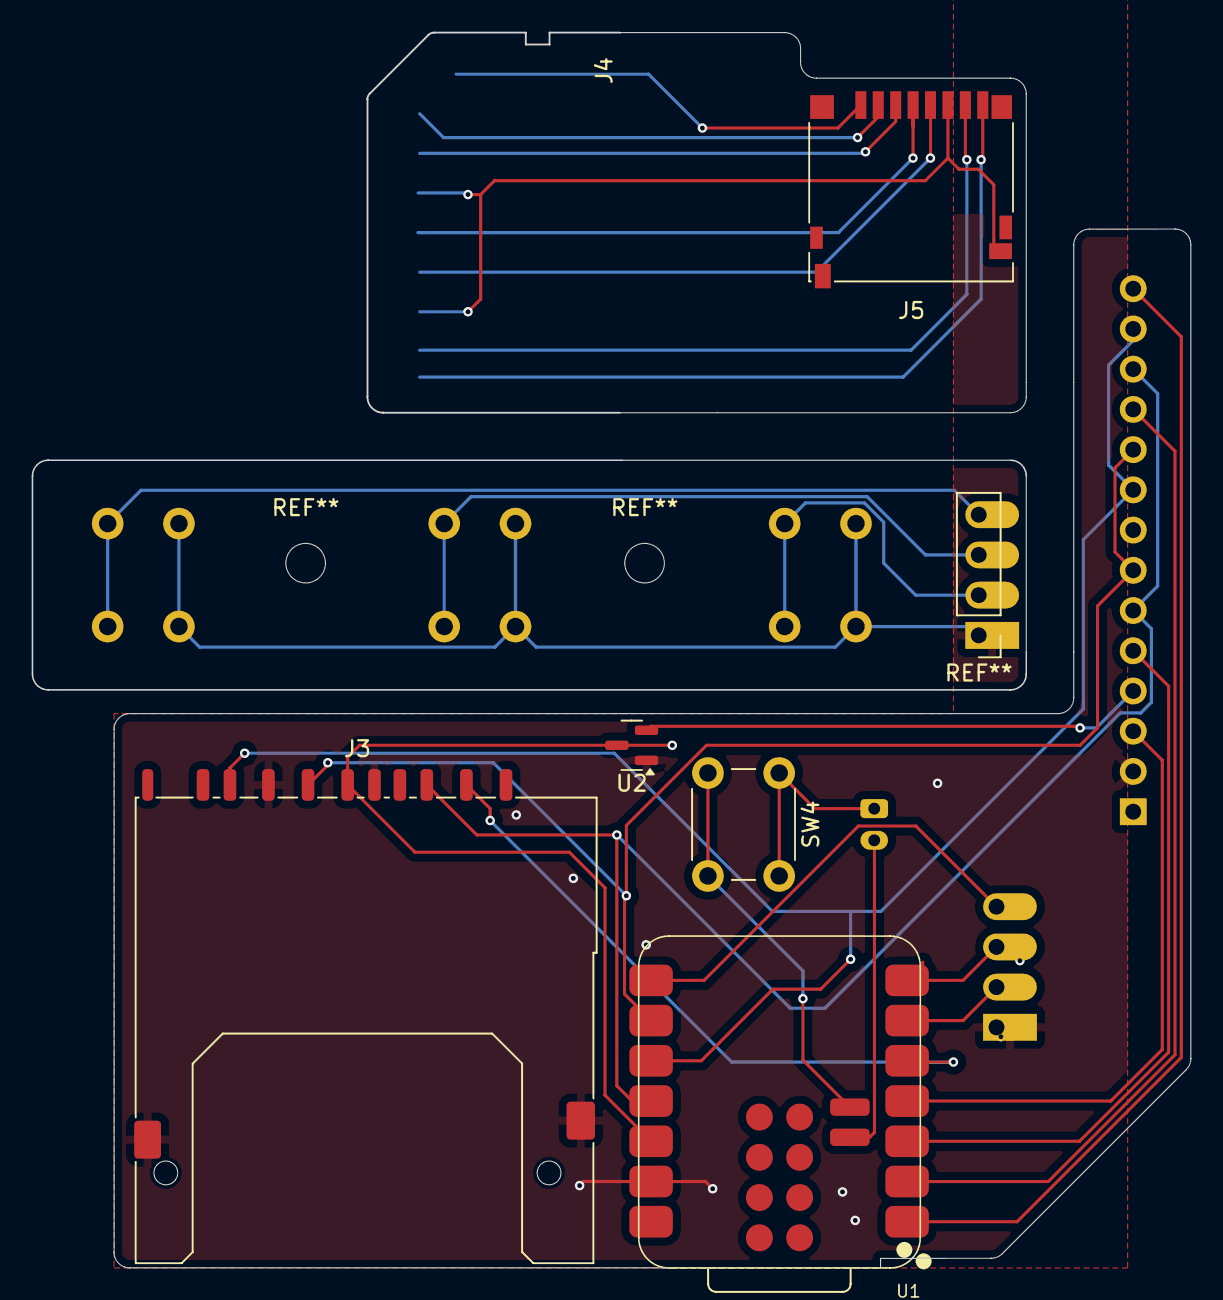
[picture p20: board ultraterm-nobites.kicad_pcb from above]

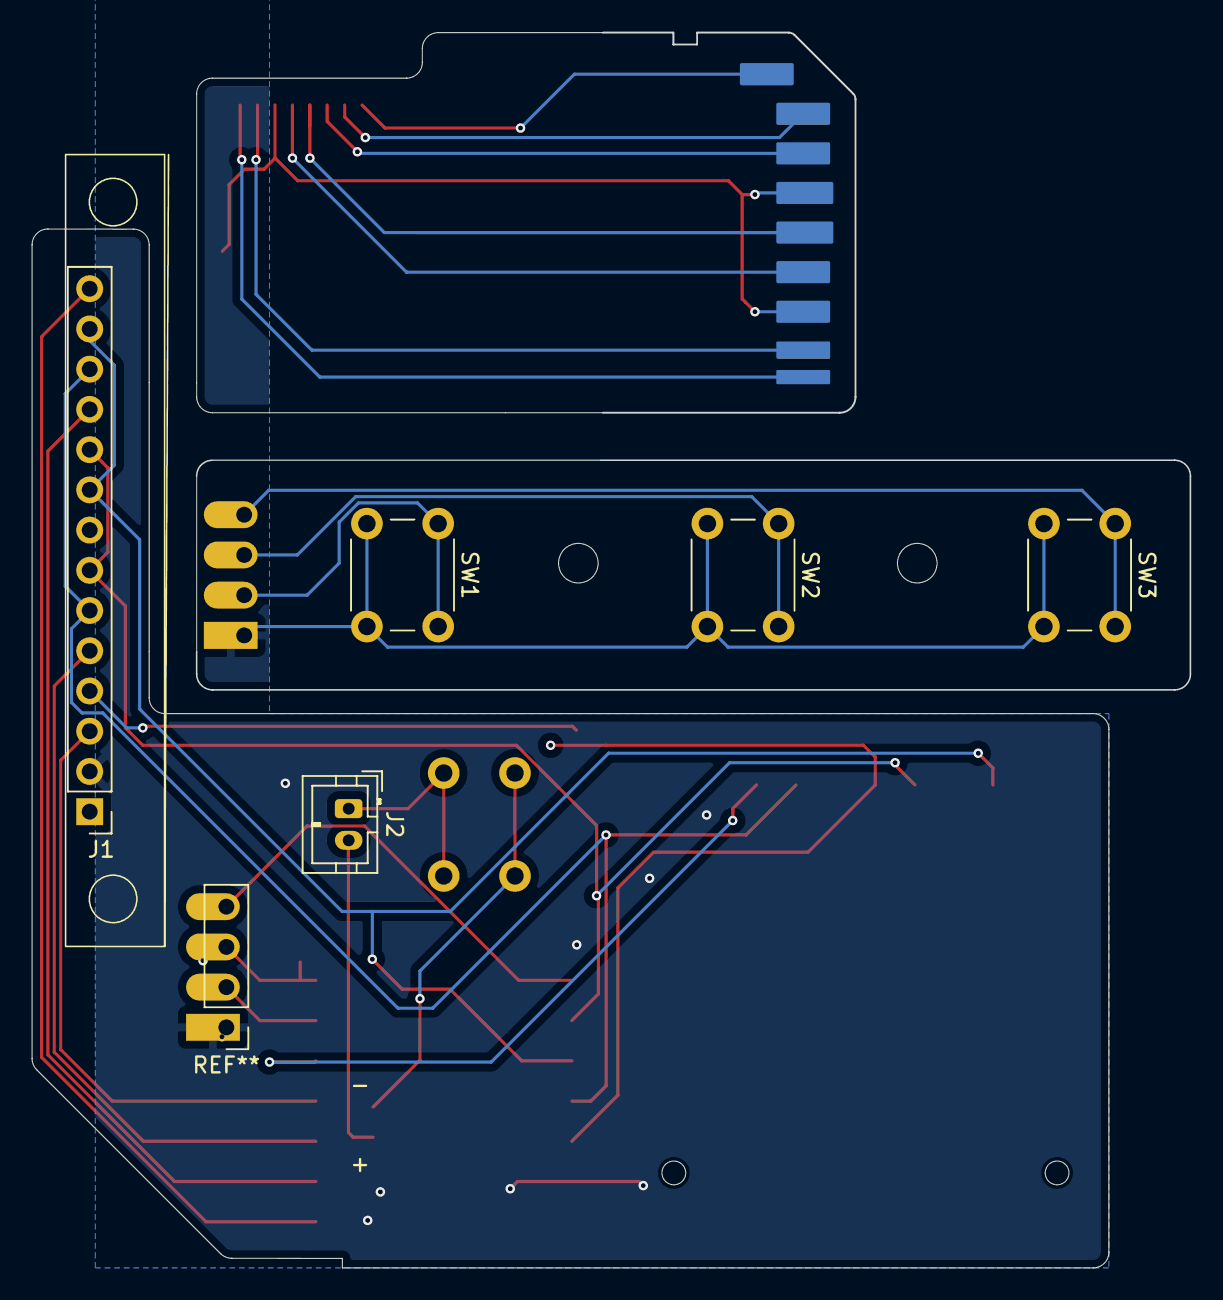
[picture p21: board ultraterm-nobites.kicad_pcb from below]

Board: 2 copper layers, 73.1 x 78.0 mm, 11 parts (5 on the bottom side), 25 nets.

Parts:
J1: ILI9341; PinHeader_1x14_P2.54mm_Vertical
J2: Battery_plug; JST_PH_B2B-PH-K_1x02_P2.00mm_Vertical
J3: SD_Card_Receptacle; SD_Kyocera_145638009511859+
J4: SD_Card_Device; SD_Card_Device_16mm_SlotDepth
J5: Micro_SD_Card; microSD_HC_Hirose_DM3D-SF
SW1, SW2, SW3: SW_Push; SW_PUSH_6mm
SW4: SW_SPST; SW_PUSH_6mm_H13mm
U1: XIAO-ESP32-S3-SMD; XIAO-ESP32S3-SMD
U2: LM809; SOT-23

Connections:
+3V3: J1.1 (VCC), J1.8 (LED), J3.4 (VDD), U1.12 (3V3), U2.3 (VCC)
GND: J1.2 (GND), J3.3 (VSS), J3.6 (VSS), J3.12 (SHELL1), J3.13 (SHELL2), SW1.2, SW2.2, SW3.2, U1.13 (GND), U2.1 (GND)
LCD_CS: J1.3 (CS), U1.4 (GPIO4_A3_D3)
LCD_DS: J1.5 (DC/RS), U1.3 (GPIO3_A2_D2)
LCD_RES: J1.4 (RESET), U2.2 (~RESET)
MISO: J1.9 (MISO), J1.13 (T_DO), J3.7 (DAT0), U1.10 (GPIO8_A9_D9_MISO)
MOSI: J1.6 (MOSI), J1.12 (T_DIN), J3.2 (CMD), U1.11 (GPIO9_A10_D10_MOSI)
unnamed: J1.7 (SCK), J1.10 (CLK), J3.5 (CLK), U1.9 (GPIO7_A8_D8_SCK)
unnamed: J2.1, SW4.1 (A)
unnamed: J2.2, U1.16 (GND)
unnamed: J4.1 (CD/DAT3), J5.2 (DAT3/CD)
unnamed: J4.5 (CLK), J5.5 (CLK)
unnamed: J4.2 (CMD), J5.3 (CMD)
unnamed: J4.7 (DAT0), J5.7 (DAT0)
unnamed: J4.8 (DAT1), J5.8 (DAT1)
unnamed: J4.9 (DAT2), J5.1 (DAT2)
unnamed: J4.4 (VDD), J5.4 (VDD)
unnamed: J4.3 (VSS), J4.6 (VSS), J5.6 (VSS), J5.9 (SHIELD)
unnamed: SW4.2 (B), U1.15 (BAT)
SD CS: J3.1 (CD/DAT3), U1.5 (GPIO5_A4_D4_SDA)
TOUCH_CS: J1.11 (T_CS), U1.2 (GPIO2_A1_D1)
TOUCH_PEN: J1.14 (T_IRQ), U1.1 (GPIO1_A0_D0)
b1: SW1.1, U1.6 (GPIO6_A5_D5_SCL)
b2: SW2.1, U1.7 (GPIO43_A6_D6_TX)
b3: SW3.1, U1.8 (GPIO44_D7_RX)

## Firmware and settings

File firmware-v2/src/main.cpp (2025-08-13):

#include "Arduino.h"
#include "a2dp_source.h"
#include "SD.h"
#include "FS.h"
#include "SPI.h"
#include <vector>
#include <algorithm>
#include <cstring>

#define SD_CS         26
#define SPI_MOSI      18
#define SPI_MISO      19
#define SPI_SCK       22

char BT_SINK_NAME[]   = "MINIJAMBOX by Jawbone"; // sink devicename
char BT_SINK_PIN[]    = "0000";             // sink pincode
char BT_DEVICE_NAME[] = "ULTRATERM";     // source devicename


#define BTN3_PIN  14
#define BTN2_PIN  4
#define BTN1_PIN  27

// Debounce configuration and state
const unsigned long DEBOUNCE_MS = 30; // adjust if needed
static bool btn1State = HIGH, btn2State = HIGH, btn3State = HIGH, touchState = HIGH;           // debounced state
static bool btn1LastReading = HIGH, btn2LastReading = HIGH, btn3LastReading = HIGH, touchLastReading = HIGH; // last raw read
static unsigned long btn1LastChange = 0, btn2LastChange = 0, btn3LastChange = 0, touchLastChange = 0;    // last bounce time
#define TOUCH_PIN 23

File            audiofile;    // @suppress("Abstract class cannot be instantiated")
uint32_t        sampleRate;
uint32_t        bitRate;
uint8_t         channels;
uint8_t         bitsPerSample=16;
uint32_t        posDataSection;

// Playlist support
static std::vector<String> playlist; // full paths to wav files
static int currentTrack = -1;
static bool isPaused = false; // play/pause state

// Forward declarations for track navigation used in input handler
bool openNextTrack();
bool openPreviousTrack();

void input_init() {
    pinMode(BTN1_PIN, INPUT_PULLUP);
    pinMode(BTN2_PIN, INPUT_PULLUP);
    pinMode(BTN3_PIN, INPUT_PULLUP);
    pinMode(TOUCH_PIN, INPUT_PULLUP);

    btn1State = btn1LastReading = digitalRead(BTN1_PIN);
    btn2State = btn2LastReading = digitalRead(BTN2_PIN);
    btn3State = btn3LastReading = digitalRead(BTN3_PIN);
    touchState = touchLastReading = digitalRead(TOUCH_PIN);
    btn1LastChange = btn2LastChange = btn3LastChange = touchLastChange = millis();
}

void handle_input() {
    unsigned long now = millis();

    bool r1 = digitalRead(BTN1_PIN);
    if (r1 != btn1LastReading) { btn1LastReading = r1; btn1LastChange = now; }
    if ((now - btn1LastChange) > DEBOUNCE_MS) {
        if (r1 != btn1State) {
            btn1State = r1;
            if (btn1State == LOW) {
                Serial.println("Button 1 pressed -> Next track");
                openPreviousTrack();
            }
        }
    }

    bool r2 = digitalRead(BTN2_PIN);
    if (r2 != btn2LastReading) { btn2LastReading = r2; btn2LastChange = now; }
    if ((now - btn2LastChange) > DEBOUNCE_MS) {
        if (r2 != btn2State) {
            btn2State = r2;
            if (btn2State == LOW) {
                Serial.println("Button 2 pressed -> Previous track");
                openNextTrack();
            }
        }
    }

    bool r3 = digitalRead(BTN3_PIN);
    if (r3 != btn3LastReading) { btn3LastReading = r3; btn3LastChange = now; }
    if ((now - btn3LastChange) > DEBOUNCE_MS) {
        if (r3 != btn3State) {
            btn3State = r3;
            if (btn3State == LOW) {
                isPaused = !isPaused;
                Serial.println(isPaused ? "Button 3 pressed -> Paused" : "Button 3 pressed -> Playing");
            }
        }
    }

    // Optional: touch input (kept commented)
    // bool touch = (digitalRead(TOUCH_PIN));
    // if (touch != touchLastReading) { touchLastReading = touch; touchLastChange = now; }
    // if ((now - touchLastChange) > DEBOUNCE_MS) {
    //     if (touch != touchState) {
    //         touchState = touch;
    //         if (touchState == LOW) {
    //             Serial.println("Touch detected");
    //         }
    //     }
    // }
}

bool parseWAV(fs::FS &fs, String path){
    char chbuf[256];
    audiofile=fs.open(path.c_str());
    String afn = (String)audiofile.name();  //audioFileName

    if(afn.endsWith(".wav")) {
        audiofile.readBytes(chbuf, 4); // read RIFF tag
        if ((chbuf[0] != 'R') || (chbuf[1] != 'I') || (chbuf[2] != 'F') || (chbuf[3] != 'F')){
            Serial.println("file has no RIFF tag");
            audiofile.seek(0);
            return false;
        }

        audiofile.readBytes(chbuf, 4); // read chunkSize (datalen)
        uint32_t cs = (uint32_t)(chbuf[0] + (chbuf[1] <<8) + (chbuf[2] <<16) + (chbuf[3] <<24) - 8);

        audiofile.readBytes(chbuf, 4); /* read wav-format */ chbuf[5] = 0;
        if ((chbuf[0] != 'W') || (chbuf[1] != 'A') || (chbuf[2] != 'V') || (chbuf[3] != 'E')){
            Serial.println("format tag is not WAVE");
            audiofile.seek(0);
            return false;
        }

        while(true){ // skip wave chunks, seek for fmt element
            audiofile.readBytes(chbuf, 4); /* read wav-format */
            if ((chbuf[0] == 'f') && (chbuf[1] == 'm') && (chbuf[2] == 't')){
                //if(audio_info) audio_info("format tag found");
                break;
            }
        }

        audiofile.readBytes(chbuf, 4); // fmt chunksize
        cs = (uint32_t) (chbuf[0] + (chbuf[1] <<8));
        if(cs>40) return false; //something is wrong
        uint8_t bts=cs-16; // bytes to skip if fmt chunk is >16
        audiofile.readBytes(chbuf, 16);
        uint16_t fc  = (uint16_t)(chbuf[0]  + (chbuf[1] <<8));  // Format code
        uint16_t nic = (uint16_t)(chbuf[2]  + (chbuf[3] <<8));  // Number of interleaved channels
        uint32_t sr  = (uint32_t)(chbuf[4]  + (chbuf[5] <<8) + (chbuf[6]  <<16) + (chbuf[7]  <<24)); // Smpling rate
        uint32_t dr  = (uint32_t)(chbuf[8]  + (chbuf[9] <<8) + (chbuf[10] <<16) + (chbuf[11] <<24)); // Data rate
        uint16_t dbs = (uint16_t)(chbuf[12] + (chbuf[13] <<8));  // Data block size
        uint16_t bps = (uint16_t)(chbuf[14] + (chbuf[15] <<8));  // Bits per sample
        Serial.printf("FormatCode=%u\n", fc);
        Serial.printf("Channel=%u\n", nic);
        Serial.printf("SampleRate=%u\n", sr);
        Serial.printf("DataRate=%u\n", dr);
        Serial.printf("DataBlockSize=%u\n", dbs);
        Serial.printf("BitsPerSample=%u\n", bps);


        if(fc != 1){
            Serial.println("format code is not 1 (PCM)");
            return false;
        }

        if(nic != 1 && nic != 2){
            Serial.print("number of channels must be 1 or 2");
            return false;
        }

        if(bps != 8 && bps !=16){
            Serial.println("bits per sample must be 8 or 16");
            return false;
        }
        bitsPerSample=bps;
        channels = nic;
        sampleRate = sr;
        bitRate = nic * sr * bps;
        Serial.printf("BitRate=%u\n", bitRate);

        audiofile.readBytes(chbuf, bts); // skip to data
        uint32_t s = audiofile.position();
        //here can be extra info, seek for data;
        while(true){
            audiofile.seek(s);
            audiofile.readBytes(chbuf, 4); /* read header signature */
            if ((chbuf[0] == 'd') && (chbuf[1] == 'a') && (chbuf[2] == 't') && (chbuf[3] == 'a')) break;
            s++;
        }

        audiofile.readBytes(chbuf, 4); // read chunkSize (datalen)
        cs = chbuf[0] + (chbuf[1] <<8) + (chbuf[2] <<16) + (chbuf[3] <<24) - 44;
        sprintf(chbuf, "DataLength=%u\n", cs);
        Serial.print(chbuf);
        posDataSection = audiofile.position();
        // Ensure file position is at the start of data
        audiofile.seek(posDataSection);
        return true;
    }
    return false;
}

void listWavFiles(fs::FS &fs, const char* dirname){
    Serial.printf("Top-level WAV files in %s\n", dirname);
    File root = fs.open(dirname);
    if(!root || !root.isDirectory()){
        Serial.println("Failed to open directory");
        return;
    }
    File entry = root.openNextFile();
    while(entry){
        if(!entry.isDirectory()){
            String name = String(entry.name());
            if((name.endsWith(".wav") || name.endsWith(".WAV")) && !name.startsWith("._") && !name.startsWith(".")){
                String path = String(dirname);
                if(!path.endsWith("/")) path += "/";
                path += name;
                Serial.printf("- %s (%u bytes)\n", path.c_str(), (unsigned int)entry.size());
            }
        }
        entry = root.openNextFile();
    }
}

// Build playlist of WAV files (top-level) and sort alphabetically
void buildPlaylist(fs::FS &fs, const char* dirname){
    playlist.clear();
    File root = fs.open(dirname);
    if(!root || !root.isDirectory()){
        Serial.println("Failed to open directory for playlist");
        return;
    }
    File entry = root.openNextFile();
    while(entry){
        if(!entry.isDirectory()){
            String name = String(entry.name());
            if((name.endsWith(".wav") || name.endsWith(".WAV")) && !name.startsWith("._") && !name.startsWith(".")){
                String path = String(dirname);
                if(!path.endsWith("/")) path += "/";
                path += name;
                playlist.push_back(path);
            }
        }
        entry = root.openNextFile();
    }
    std::sort(playlist.begin(), playlist.end(), [](const String& a, const String& b){
        return a.compareTo(b) < 0;
    });
    Serial.printf("Playlist contains %u tracks\n", (unsigned int)playlist.size());
    for (size_t i = 0; i < playlist.size(); ++i){
        Serial.printf("  %2u: %s\n", (unsigned int)i, playlist[i].c_str());
    }
}

bool openTrackByIndex(int idx){
    if(idx < 0 || idx >= (int)playlist.size()) return false;
    if(audiofile) audiofile.close();
    const String& path = playlist[idx];
    Serial.printf("Opening track %d: %s\n", idx, path.c_str());
    bool ok = parseWAV(SD, path);
    if(ok){
        // Ensure we are at data start
        audiofile.seek(posDataSection);
    }
    return ok;
}

bool openNextTrack(){
    if(playlist.empty()) return false;
    currentTrack = (currentTrack + 1) % (int)playlist.size();
    return openTrackByIndex(currentTrack);
}

// New: open previous track (wrap-around)
bool openPreviousTrack(){
    if(playlist.empty()) return false;
    currentTrack = (currentTrack - 1 + (int)playlist.size()) % (int)playlist.size();
    return openTrackByIndex(currentTrack);
}

void setup(){
    Serial.begin(115200);
    SPI.begin(SPI_SCK, SPI_MISO, SPI_MOSI);
    SD.begin(SD_CS);
    listWavFiles(SD, "/");
    buildPlaylist(SD, "/");
    if(!playlist.empty()){
        currentTrack = 0;
        if(!openTrackByIndex(currentTrack)){
            Serial.println("Failed to open first track");
        }
    } else {
        Serial.println("No WAV files found on SD");
    }
    input_init();
    a2dp_source_init(BT_SINK_NAME, BT_SINK_PIN);
}


void loop(){
    bt_loop();
    handle_input();
}

int32_t bt_data(uint8_t *data, int32_t len, uint32_t* sr){
    *sr = sampleRate;
    if (len < 0 || data == NULL) {
        return 0;
    }

    // When paused, send silence to keep the stream alive
    if (isPaused) {
        memset(data, 0, (size_t)len);
        return len;
    }

    int32_t readLen = audiofile.read(data, len);
    if(readLen == 0){
        // End of current track, advance to next and try again
        if(openNextTrack()){
            readLen = audiofile.read(data, len);
        } else {
            return 0;
        }
    }
    return readLen;
}
void bt_info(const char* info){
    Serial.printf("bt_info: %s\n", info);
}

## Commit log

2025-05-20 Planning stages still
2025-06-28 added literally all the pcb files because i forgot
    [XIAO-ESP32S3 v2.step, cyberterm.obj, ultraterm.kicad_pcb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]
2025-07-03 fiddled with PCB for export
    [XIAO-ESP32S3 v2.step, pcb.step, pcb.stl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]
2025-07-03 Semifinal case design
2025-07-03 Revised for TINYPICO
    [10067847-001RLF.step, bom.csv, designators.csv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]
2025-07-05 IO seems good?
    [ultraterm.kicad_pcb]
2025-07-06 Final case ver.
2025-07-06 Final beta firmware.
    [ultraterm.kicad_pcb, ultraterm.kicad_sch]
2025-07-07 this might fix the csv
    [BOM.CSV]
2025-08-07 commit before i start scrwing with stuff again
    [bom.csv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]
2025-08-13 added assembly photos
2025-08-13 playlist, skipping, pause all functional
    [main.cpp]
